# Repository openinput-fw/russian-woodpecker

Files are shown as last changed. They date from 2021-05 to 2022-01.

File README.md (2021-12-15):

# russian-woodpecker



[](https://github.com/openinput-fw)

*russian-woodpecker* is a usb HS (capable of 8kHz polling rate) 2.4GHz radio receiver dongle for use with input devices.

Please see the [documentation](https://russian-woodpecker.readthedocs.io/en/latest)
for more information.

## Specifications
- 8 kHz polling rate suppor
- 2.4GHz radio
- smol, but not that smol

## License

This hardware is licensed under the [CERN-OHL-P v2](LICENSE) license.

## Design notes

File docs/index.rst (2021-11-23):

:hide-toc:

******************
russian-woodpecker
******************
*russian-woodpecker* is a usb HS (capable of 8kHz polling rate) 2.4GHz radio receiver dongle for use with input devices

State of the project
====================

First prototype.

.. admonition:: Roadmap

   - Initial design |:+1:|
   - First prototype manufactured and assembled |:hammer:|
   - Barebones firmware support
   - Documentation |:hammer:|
   - Hardware improvements / V1

   ========== ================
   |:+1:|     Done!
   |:hammer:| Work in progress
   ========== ================

Specifications
==============

* 8 kHz polling rate suppor
* 2.4GHz radio
* smol, but not that smol

Hardware
========

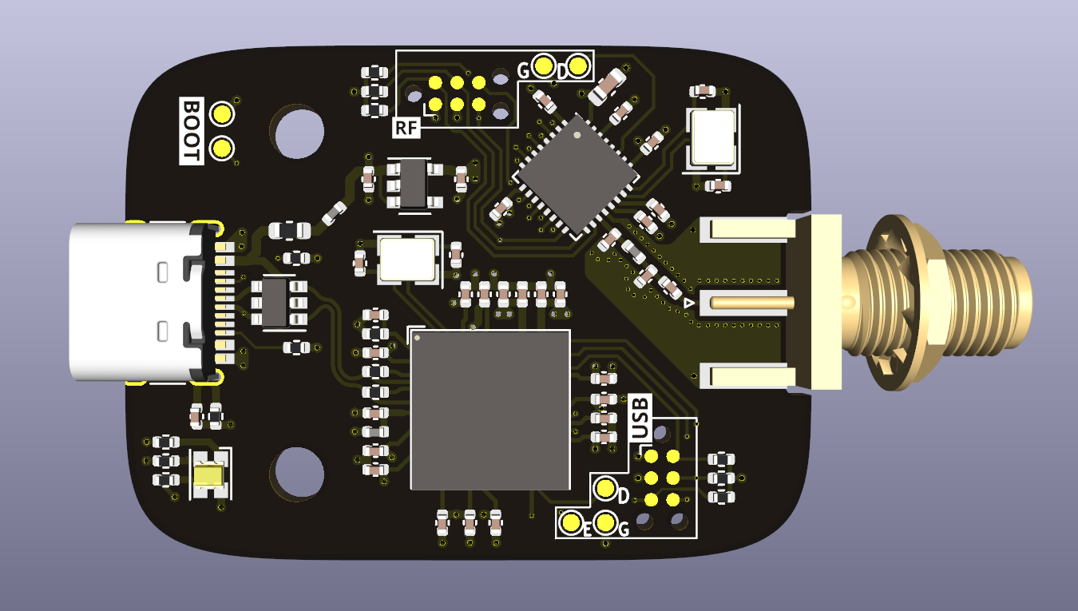
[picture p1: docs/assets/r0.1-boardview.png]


* ATSAMS3U MCU as main controller
* nrf52810 MCU as radio receiver
   * SPI connection between MCUs
* USB C connector
* External antenna connector

Firmware
========

The plan:

The device will need two firmwares, nrf52 will be updated through a spi bootloader by the main mcu, which will be updated through hid

Both will include debug header

.. toctree::
   :caption: External Links
   :hidden:

   Source <https://github.com/openinput-fw/russian-woodpecker>
   Firmware <https://openinput.readthedocs.io>
   Issue Tracker <https://github.com/openinput-fw/russian-woodpecker/issues>

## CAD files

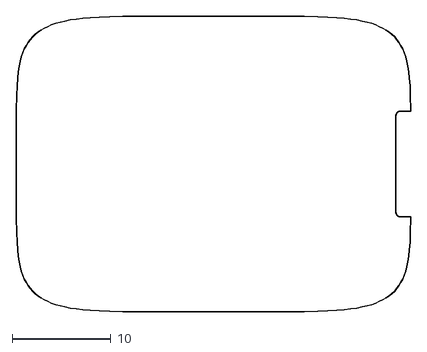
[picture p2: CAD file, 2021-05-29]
cad/outline.dxf
40.0 x 30.0

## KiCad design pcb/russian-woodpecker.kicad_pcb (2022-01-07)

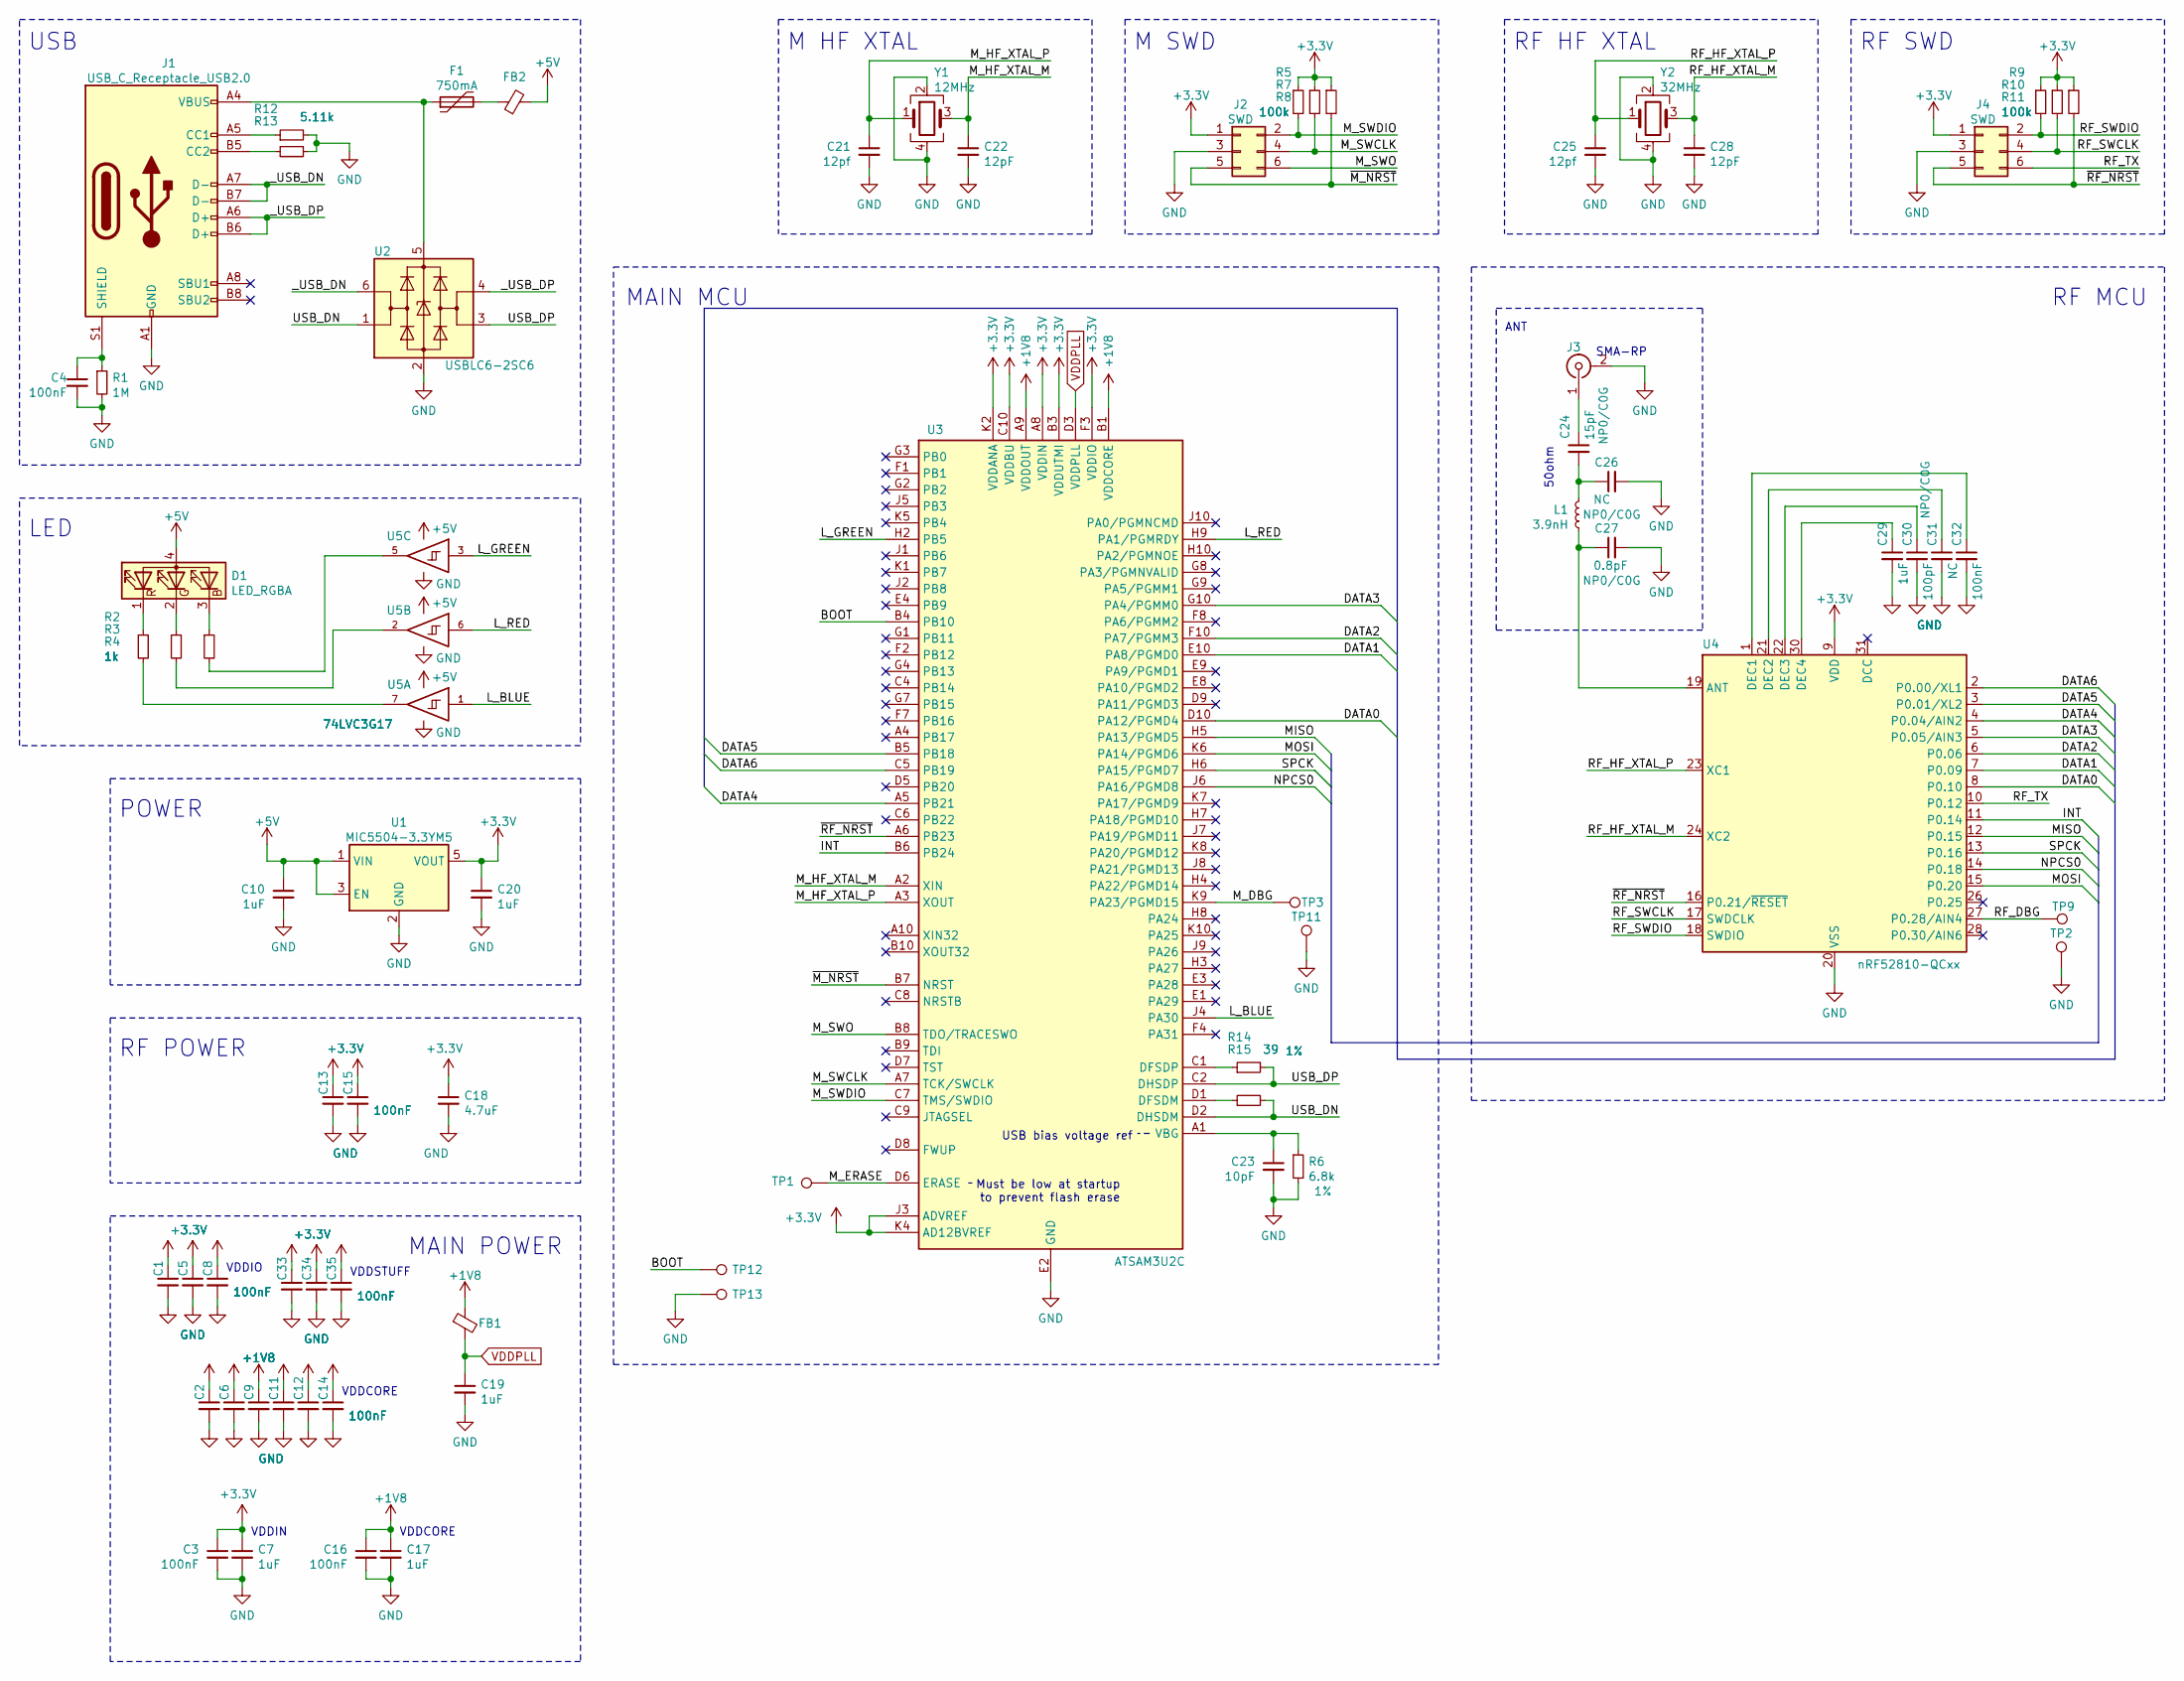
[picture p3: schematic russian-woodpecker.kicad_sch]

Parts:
C1, C2, C3, C4, C5, C6, C8, C9, C11, C12, C13, C14, C15, C16, C32, C33, C34, C35: 100nF; C_0402_1005Metric
C7, C10, C17, C19, C20, C29: 1uF; C_0402_1005Metric
C18: 4.7uF; C_0603_1608Metric
C21, C25: 12pf; C_0402_1005Metric
C22, C28: 12pF; C_0402_1005Metric
C23: 10pF; C_0402_1005Metric
C24: 15pF; C_0402_1005Metric
C26, C31: NC; C_0402_1005Metric
C27: 0.8pF; C_0402_1005Metric
C30: 100pF; C_0402_1005Metric
D1: LED_RGBA; LED_LiteOn_LTST-C19HE1WT
F1: 750mA; Fuse_0603_1608Metric
FB1, FB2: L_0402_1005Metric
J1: USB_C_Receptacle_USB2.0; USB_C_Receptacle_HRO_TYPE-C-31-M-12
J2, J4: SWD; Tag-Connect_TC2030-IDC-NL_2x03_P1.27mm_Vertical
J3: SMA-RP; SMA_Amphenol_132289_EdgeMount
L1: 3.9nH; L_0402_1005Metric
R1: 1M; R_0402_1005Metric
R2, R3, R4: 1k; R_0402_1005Metric
R5, R7, R8, R9, R10, R11: 100k; R_0402_1005Metric
R6: 6.8k; R_0402_1005Metric; Tolerance 1%
R12, R13: 5.11k; R_0402_1005Metric
R14, R15: 39; R_0402_1005Metric; Tolerance 1%
TP1, TP2, TP3, TP9, TP11, TP12, TP13: TestPoint_Pad_D1.0mm
U1: MIC5504-3.3YM5; SOT-23-5
U2: USBLC6-2SC6; SOT-23-6
U3: ATSAM3U2C; TFBGA-100_9.0x9.0mm_Layout10x10_P0.8mm
U4: nRF52810-QCxx; QFN-32-1EP_5x5mm_P0.5mm_EP3.6x3.6mm
U5: 74LVC3G17; VSSOP-8_2.3x2mm_P0.5mm
Y1: 12MHz; Crystal_SMD_3225-4Pin_3.2x2.5mm
Y2: 32MHz; Crystal_SMD_3225-4Pin_3.2x2.5mm

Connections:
+1V8: C2.1, C6.1, C9.1, C11.1, C12.1, C14.1, C16.1, C17.1, FB1.1, U3.A9 (VDDOUT), U3.B1 (VDDCORE), U3.D4 (VDDCORE), U3.E7 (VDDCORE), U3.F9 (VDDCORE), U3.G5 (VDDCORE), U3.H1 (VDDCORE)
+3V3: C1.1, C3.1, C5.1, C7.1, C8.1, C13.1, C15.1, C18.1, C20.1, C33.1, C34.1, C35.1, J2.1, J4.1, R5.1, R7.1, R8.1, R9.1, R10.1, R11.1, U1.5 (VOUT), U3.A8 (VDDIN), U3.B3 (VDDUTMI), U3.C10 (VDDBU), U3.E6 (VDDIO), U3.F3 (VDDIO), U3.F5 (VDDIO), U3.J3 (ADVREF), U3.K2 (VDDANA), U3.K4 (AD12BVREF), U4.9 (VDD), U4.25 (VDD), U4.32 (VDD)
+5V: C10.1, D1.4 (A), FB2.2, U1.1 (VIN), U1.3 (EN), U5.8 (VCC)
/BOOT: TP12.1, U3.B4 (PB10)
/DATA0: U3.D10 (PA12/PGMD4), U4.8 (P0.10)
/DATA1: U3.E10 (PA8/PGMD0), U4.7 (P0.09)
/DATA2: U3.F10 (PA7/PGMM3), U4.6 (P0.06)
/DATA3: U3.G10 (PA4/PGMM0), U4.5 (P0.05/AIN3)
/DATA4: U3.A5 (PB21), U4.4 (P0.04/AIN2)
/DATA5: U3.B5 (PB18), U4.3 (P0.01/XL2)
/DATA6: U3.C5 (PB19), U4.2 (P0.00/XL1)
/INT: U3.B6 (PB24), U4.11 (P0.14)
/L_BLUE: U3.J4 (PA30), U5.1
/L_GREEN: U3.H2 (PB5), U5.3
/L_RED: U3.H9 (PA1/PGMRDY), U5.6
/MISO: U3.H5 (PA13/PGMD5), U4.12 (P0.15)
/MOSI: U3.K6 (PA14/PGMD6), U4.15 (P0.20)
/M_DBG: TP3.1, U3.K9 (PA23/PGMD15)
/M_ERASE: TP1.1, U3.D6 (ERASE)
/M_HF_XTAL_M: C22.1, U3.A2 (XIN), Y1.3
/M_HF_XTAL_P: C21.1, U3.A3 (XOUT), Y1.1
/M_SWCLK: J2.4, R7.2, U3.A7 (TCK/SWCLK)
/M_SWDIO: J2.2, R5.2, U3.C7 (TMS/SWDIO)
/M_SWO: J2.6, U3.B8 (TDO/TRACESWO)
/NPCS0: U3.J6 (PA16/PGMD8), U4.14 (P0.18)
/RF_DBG: TP9.1, U4.27 (P0.28/AIN4)
/RF_HF_XTAL_M: C28.1, U4.24 (XC2), Y2.3
/RF_HF_XTAL_P: C25.1, U4.23 (XC1), Y2.1
/RF_SWCLK: J4.4, R10.2, U4.17 (SWDCLK)
/RF_SWDIO: J4.2, R9.2, U4.18 (SWDIO)
/RF_TX: J4.6, U4.10 (P0.12)
/SPCK: U3.H6 (PA15/PGMD7), U4.13 (P0.16)
/USB_DN: R15.2, U2.1 (I/O1), U3.D2 (DHSDM)
/USB_DP: R14.2, U2.3 (I/O2), U3.C2 (DHSDP)
/_USB_DN: J1.A7 (D-), J1.B7 (D-), U2.6 (I/O1)
/_USB_DP: J1.A6 (D+), J1.B6 (D+), U2.4 (I/O2)
/~M_NRST: J2.5, R8.2, U3.B7 (NRST)
/~RF_NRST: J4.5, R11.2, U3.A6 (PB23), U4.16 (P0.21/~RESET)
GND: C1.2, C2.2, C3.2, C4.2, C5.2, C6.2, C7.2, C8.2, C9.2, C10.2, C11.2, C12.2, C13.2, C14.2, C15.2, C16.2, C17.2, C18.2, C19.2, C20.2, C21.2, C22.2, C23.2, C25.2, C26.2, C27.2, C28.2, C29.2, C30.2, C31.2, C32.2, C33.2, C34.2, C35.2, J1.A1 (GND), J1.A12 (GND), J1.B1 (GND), J1.B12 (GND), J2.3, J3.2 (Ext), J4.3, R1.2, R6.2, R12.2, R13.2, TP2.1, TP11.1, TP13.1, U1.2 (GND), U2.2 (GND), U3.B2 (GNDUTMI), U3.C3 (GNDPLL), U3.E2 (GND), U3.E5 (GNDBU), U3.F6 (GND), U3.G6 (GND), U3.K3 (GNDANA), U4.20 (VSS), U4.29 (VSS), U4.33 (VSS), U5.4 (GND), Y1.2, Y1.4, Y2.2, Y2.4
unnamed: C4.1, J1.S1 (SHIELD), R1.1
unnamed: C23.1, R6.1, U3.A1 (VBG)
unnamed: C24.1, J3.1 (In)
unnamed: C24.2, C26.1, L1.2
unnamed: C27.1, L1.1, U4.19 (ANT)
unnamed: C29.1, U4.30 (DEC4)
unnamed: C30.1, U4.22 (DEC3)
unnamed: C31.1, U4.21 (DEC2)
unnamed: C32.1, U4.1 (DEC1)
unnamed: F1.1, J1.A4 (VBUS), J1.A9 (VBUS), J1.B4 (VBUS), J1.B9 (VBUS), U2.5 (VBUS)
unnamed: F1.2, FB2.1
unnamed: J1.A5 (CC1), R12.1
unnamed: J1.B5 (CC2), R13.1
unnamed: D1.1 (RK), R2.1
unnamed: R2.2, U5.7
unnamed: D1.2 (GK), R3.1
unnamed: R3.2, U5.2
unnamed: D1.3 (BK), R4.1
unnamed: R4.2, U5.5
unnamed: R14.1, U3.C1 (DFSDP)
unnamed: R15.1, U3.D1 (DFSDM)
VDDPLL: C19.1, FB1.2, U3.D3 (VDDPLL)

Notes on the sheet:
RF POWER
RF MCU
VDDIO
USB bias voltage ref
Must be low at startup to prevent flash erase
VDDCORE
USB
M SWD
RF HF XTAL
MAIN POWER
VDDSTUFF
VDDIN
RF SWD
LED
MAIN MCU
SMA-RP
M HF XTAL
POWER
ANT
50ohm

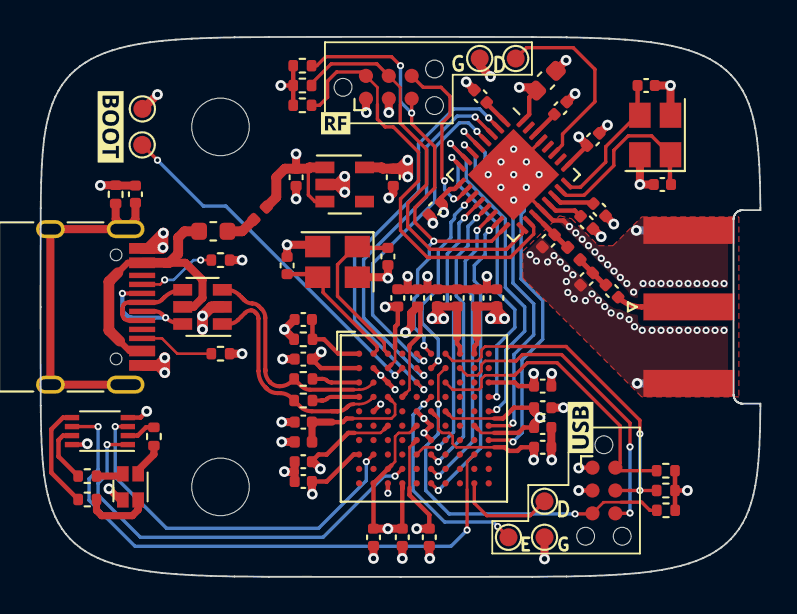
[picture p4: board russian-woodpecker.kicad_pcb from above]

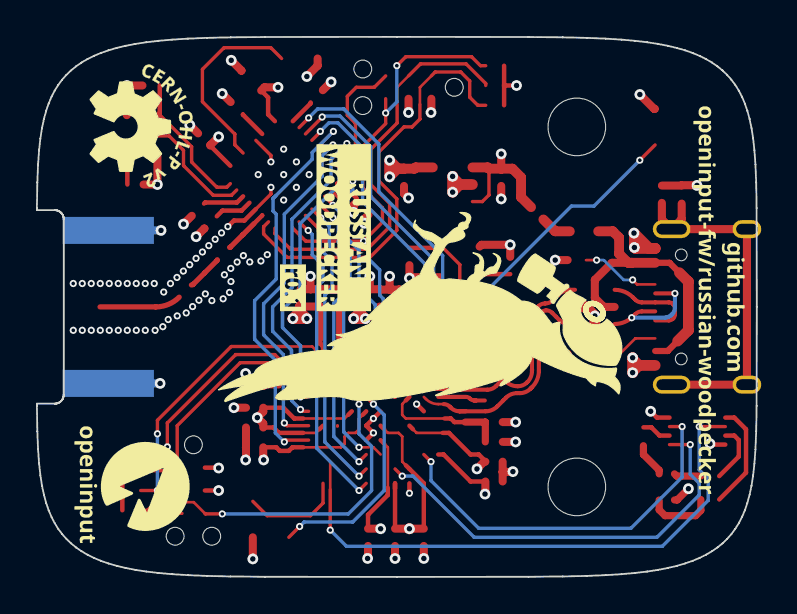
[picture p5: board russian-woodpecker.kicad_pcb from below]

Board: 4 copper layers, 40.0 x 30.0 mm, 82 parts (4 on the bottom side), 61 nets.

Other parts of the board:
MH0, MH0#2: MountingHole_3.2mm_M3
svg2mod, svg2mod#2, svg2mod#3, svg2mod#4, svg2mod#5, svg2mod#6, svg2mod#7: G***; svg2mod

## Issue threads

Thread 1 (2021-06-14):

Schematic won't open in Kicad

Gitmaster511, 2021-06-14:
I tried to open the Russian-Woodpecker file in kicad just to see the schematic but it just says error. Can you provide a .pdf of the schematic?
Thanks

perigoso, 2021-06-14:
pdf of the schematic is available in [releases](https://github.com/openinput-fw/russian-woodpecker/releases).

as for opening the schematic, where you on the kicad nightly version? this was made with the development version of kicad, which is not backwards compatible

Closed 2021-06-16.

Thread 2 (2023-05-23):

Missing inductor specs

dexter93, 2023-05-23:
Specification values missing for [`FB1`](https://github.com/openinput-fw/russian-woodpecker/blob/0385402cc100d2da4778151a18c0304d4b7dbfae/pcb/russian-woodpecker.kicad_pcb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),  [`FB2` ](https://github.com/openinput-fw/russian-woodpecker/blob/0385402cc100d2da4778151a18c0304d4b7dbfae/pcb/russian-woodpecker.kicad_pcb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)VBUS filtering inductors, only footprint is published

perigoso, 2023-05-23:
Check if it doesn't have a manufacturer part number, i don't recall, if it doesn't you can reasonably expect the value to be present on the datasheet or recommended circuit

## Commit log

2021-05-25 kicad: create kicad project
    [russian-woodpecker.kicad_pcb, russian-woodpecker.kicad_sch]
2021-05-26 kicad: add atsam3u lib
2021-05-26 sch: rev 0.1
    [russian-woodpecker.kicad_sch]
2021-05-29 kicad: add SMA connector models
2021-05-29 cad: add dxf outline (superellipsoid genned in openscad)
    [outline.dxf]
2021-05-29 gitignore: kicad: add bakup entry in gitignore
2021-05-29 pcb: add boot button, change usb to type C, initial board
    [russian-woodpecker.kicad_pcb, russian-woodpecker.kicad_sch]
2021-05-29 readme: add board view
2021-06-05 pcb: finalize routing
    [russian-woodpecker.kicad_pcb, russian-woodpecker.kicad_sch]
2021-06-08 repo: update references in preparation for transfer to openinput org
    [russian-woodpecker.kicad_pcb, russian-woodpecker.kicad_sch]
2021-06-08 pcbnew: fix 3d model references
    [russian-woodpecker.kicad_pcb]
2021-06-08 readme: add oi logo, update board view
2021-06-08 assets: remove unused board view for r0.0
2021-06-08 kicad pro: update drc preferences
2021-06-09 pcb: change led drive circuitry
    [russian-woodpecker.kicad_pcb, russian-woodpecker.kicad_sch]
2022-01-07 kicad: save pcb with v6.0
    [russian-woodpecker.kicad_pcb, russian-woodpecker.kicad_sch]

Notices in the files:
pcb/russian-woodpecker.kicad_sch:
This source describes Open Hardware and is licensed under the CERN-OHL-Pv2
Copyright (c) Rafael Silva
